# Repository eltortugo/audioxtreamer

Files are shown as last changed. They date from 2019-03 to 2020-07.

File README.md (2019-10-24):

# AudioXtreamer
A simple multichannel USB/FPGA PCM audio interface:

<p align="center">
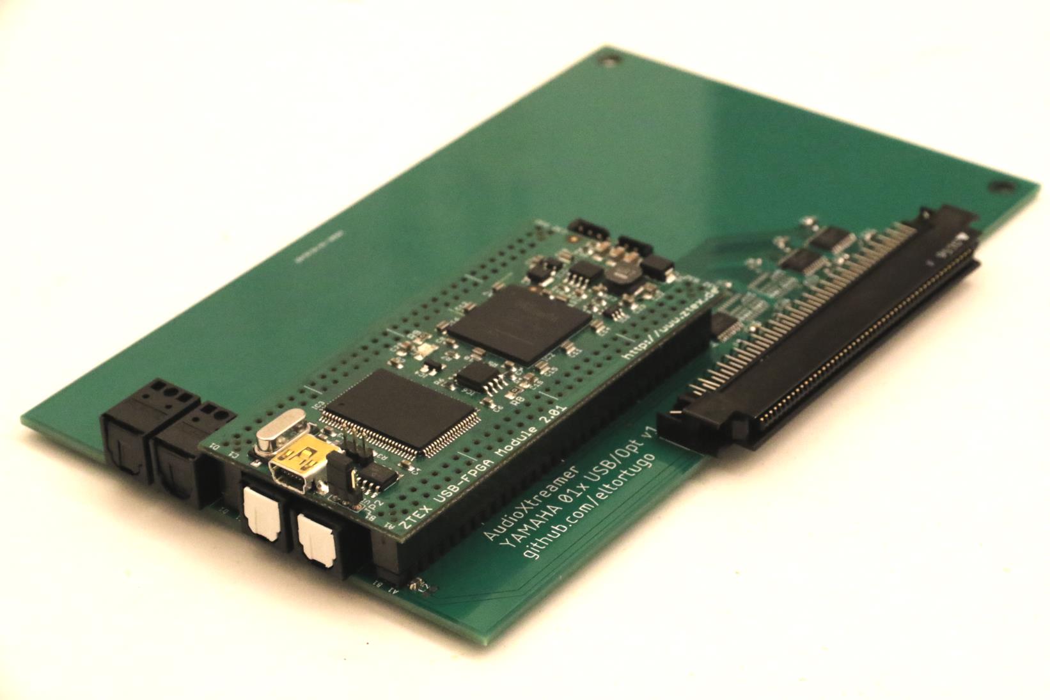
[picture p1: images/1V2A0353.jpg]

</p>

Initially started as a simple way to add usb connectivity to the Yamaha 01x firewire based digital mixer & control surface, this project attempts to provide a simple low latency ASIO interface to a usb connected fpga that handles the i2s I/O.

Inspired by [Koon](https://sites.google.com/site/koonaudioprojects/usb-to-multi-channel-usb2-0) and his 24ch out usb interface, it builds further by providing 32in/32out on a simple usb2.0 interface and bypassing any vendor specific driver to communicate with the lowest possible latency with the fpga.

The proof of concept was built and written around the ft232h usb fifo in combination with a zynq fpga but it rapidly became clear that from a practical point of view, a more flexible Cypress FX2LP and a Xilinx Spartan 6 would suffice the needs of the interface. Although the code is now fully adapted to the 16bit data bus of the Cypress and the CoreGenerator fifos of ISE, it is easily portable to the original 8 bit FTDI and the new Vivado IP generator.

The AudioXtreamer can be seen as 3 different parts:
  - A generic C++ ASIO (TortugASIO) multi-threaded 32/64 bit driver that bridges the audio client/DAW to the USB backend
  - AudioXtreamer is a simple user mode driver that uses isochronous transfers to communicate with the fx2lp, plus a tray UI to          configure asio buffer sizes, channel count and midi ports. It uses USBDk/WinUSB as backend layer to the FX2LP.
  - VHDL fpga code for the Spartan 6 which handles the usb fifos, sample buffer and generation and decoding of the PCM I/O
  
The sources are written in such a way that the user can configure how many inputs and outputs can be handled in software and hardware.
 
To build the whole project you will need basic knowledge of C/C++ and Visual Studio, VHDL and ISE plus basic digital electronics skills.
 
The hardware implementation is based on the [ZTEX 2.01](https://www.ztex.de/usb-fpga-2/usb-fpga-2.01.e.html) but simple Aliexpress fx2lp / spartan6 parts should also work with minimal effort.

Xtreamer and ZTEX module for 01x |  PCB
:-------------------------:|:-------------------------:
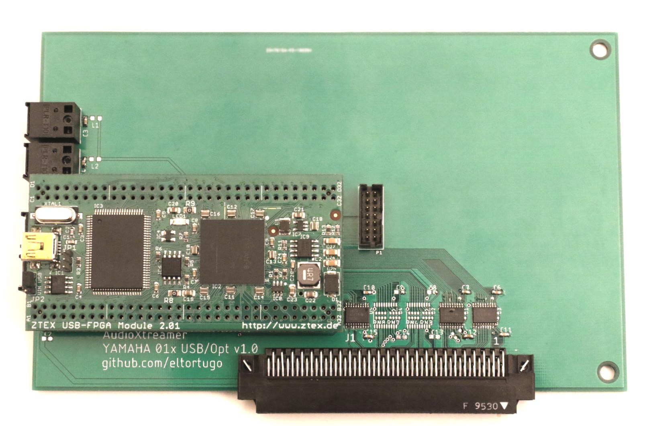
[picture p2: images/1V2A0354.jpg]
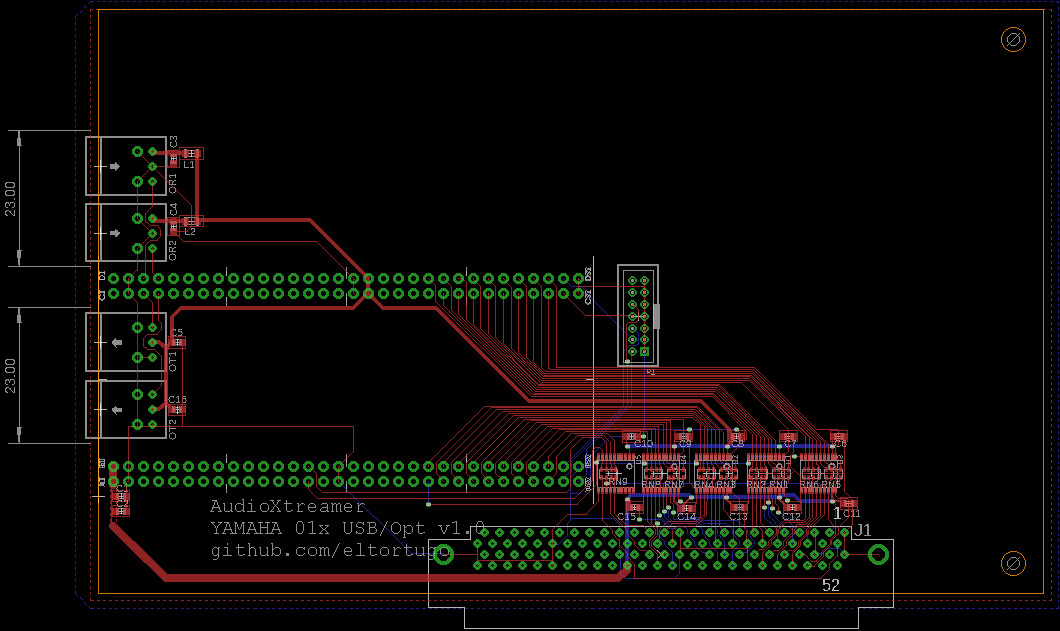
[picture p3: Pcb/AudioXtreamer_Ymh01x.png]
Gerber
  | 
  
  <p align="center">
  Yamaha 01x retrofitted with AudioXtreamer (USB/ADAT)

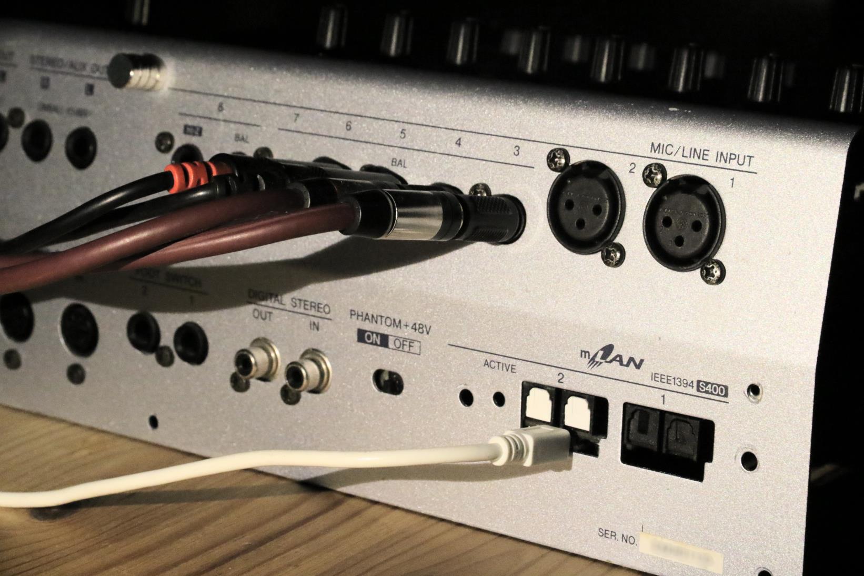
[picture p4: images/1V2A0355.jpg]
  
</p>

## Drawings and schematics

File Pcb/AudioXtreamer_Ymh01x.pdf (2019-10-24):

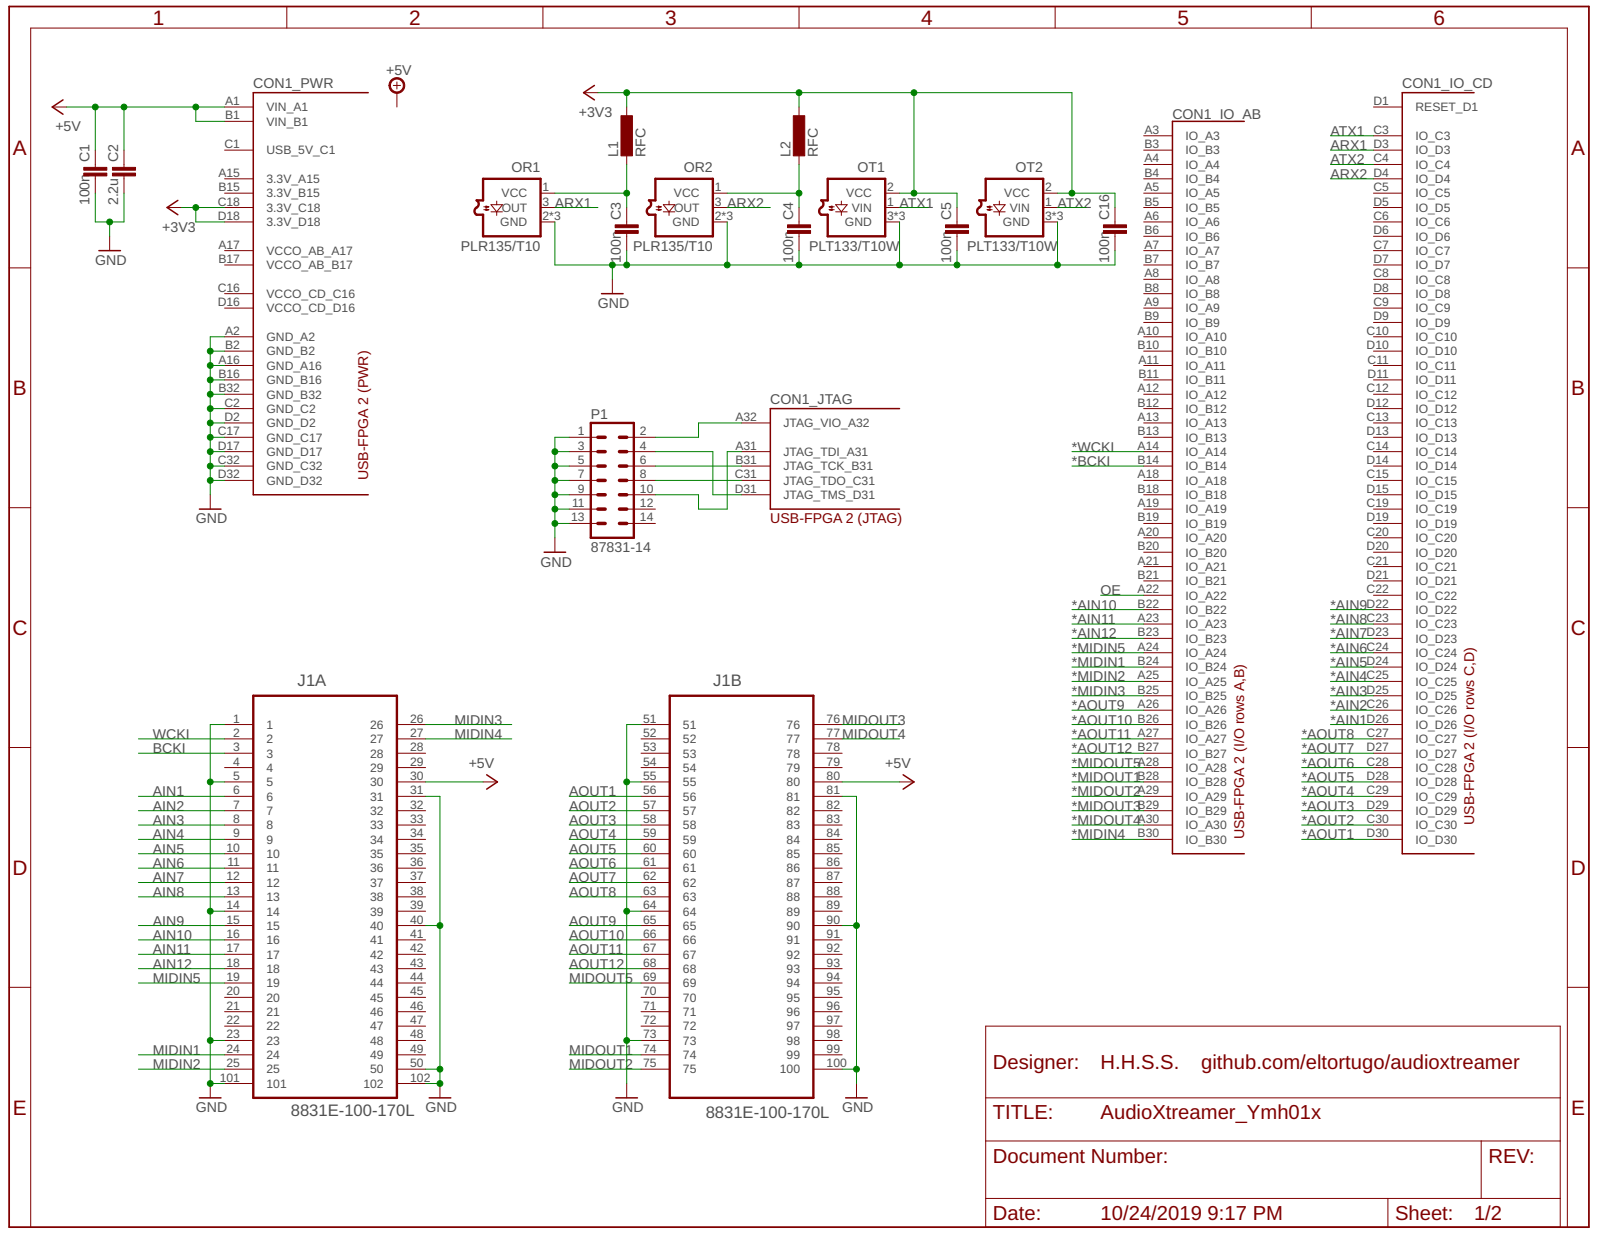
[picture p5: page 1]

Document Number: | REV:

Date: 10/24/2019 9:17 PM | Sheet: 1/2

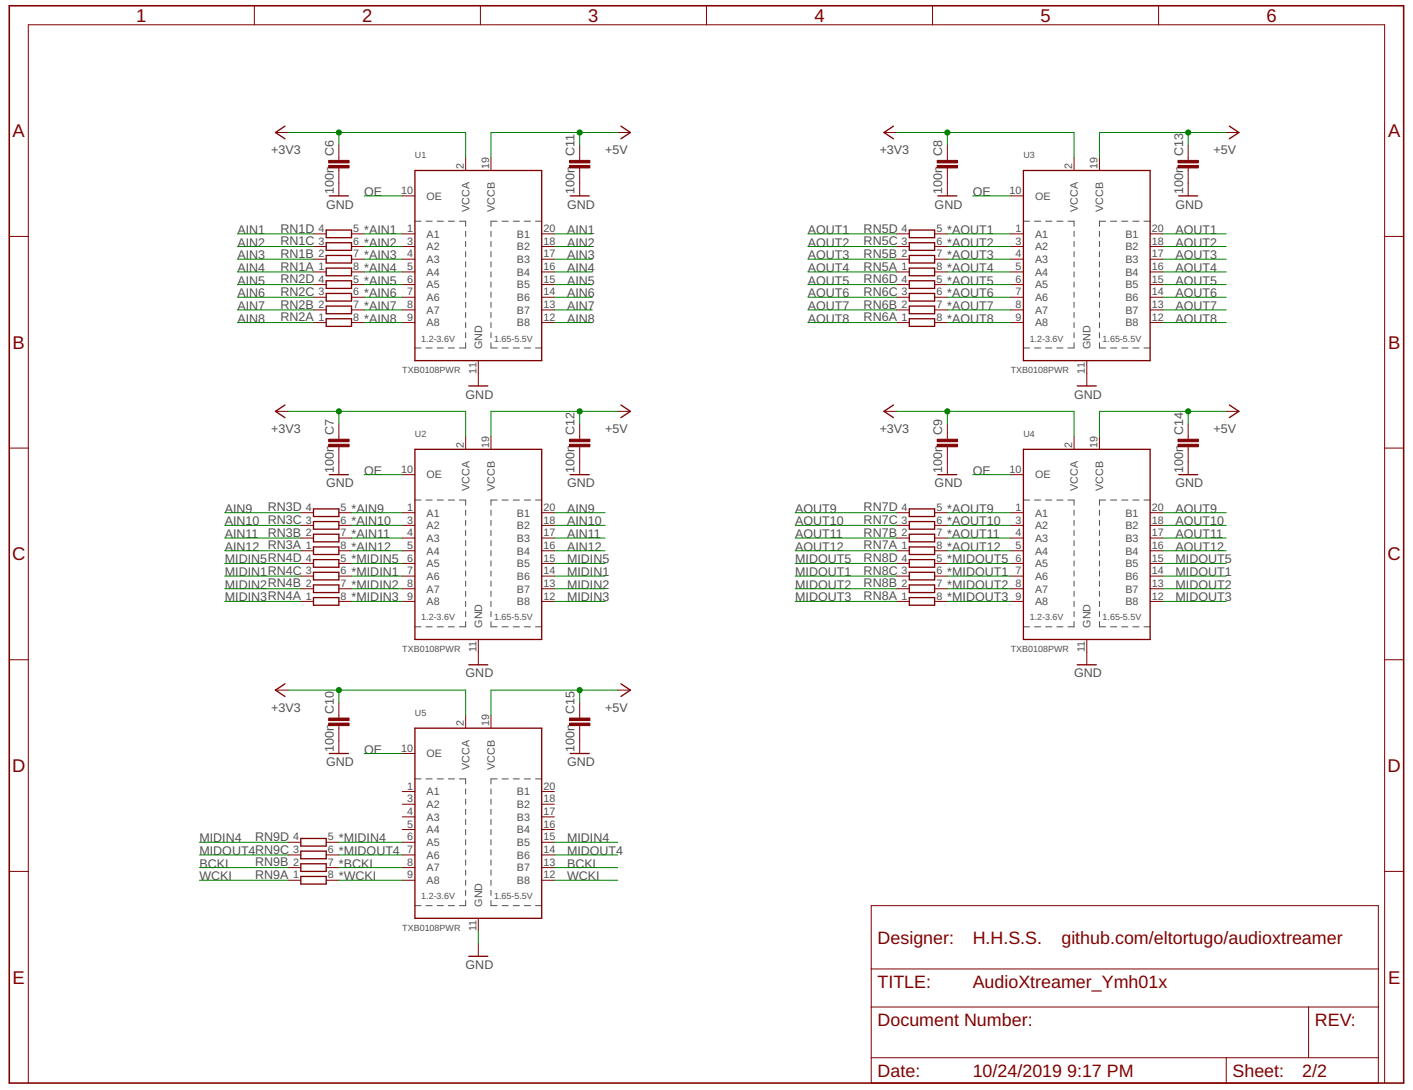
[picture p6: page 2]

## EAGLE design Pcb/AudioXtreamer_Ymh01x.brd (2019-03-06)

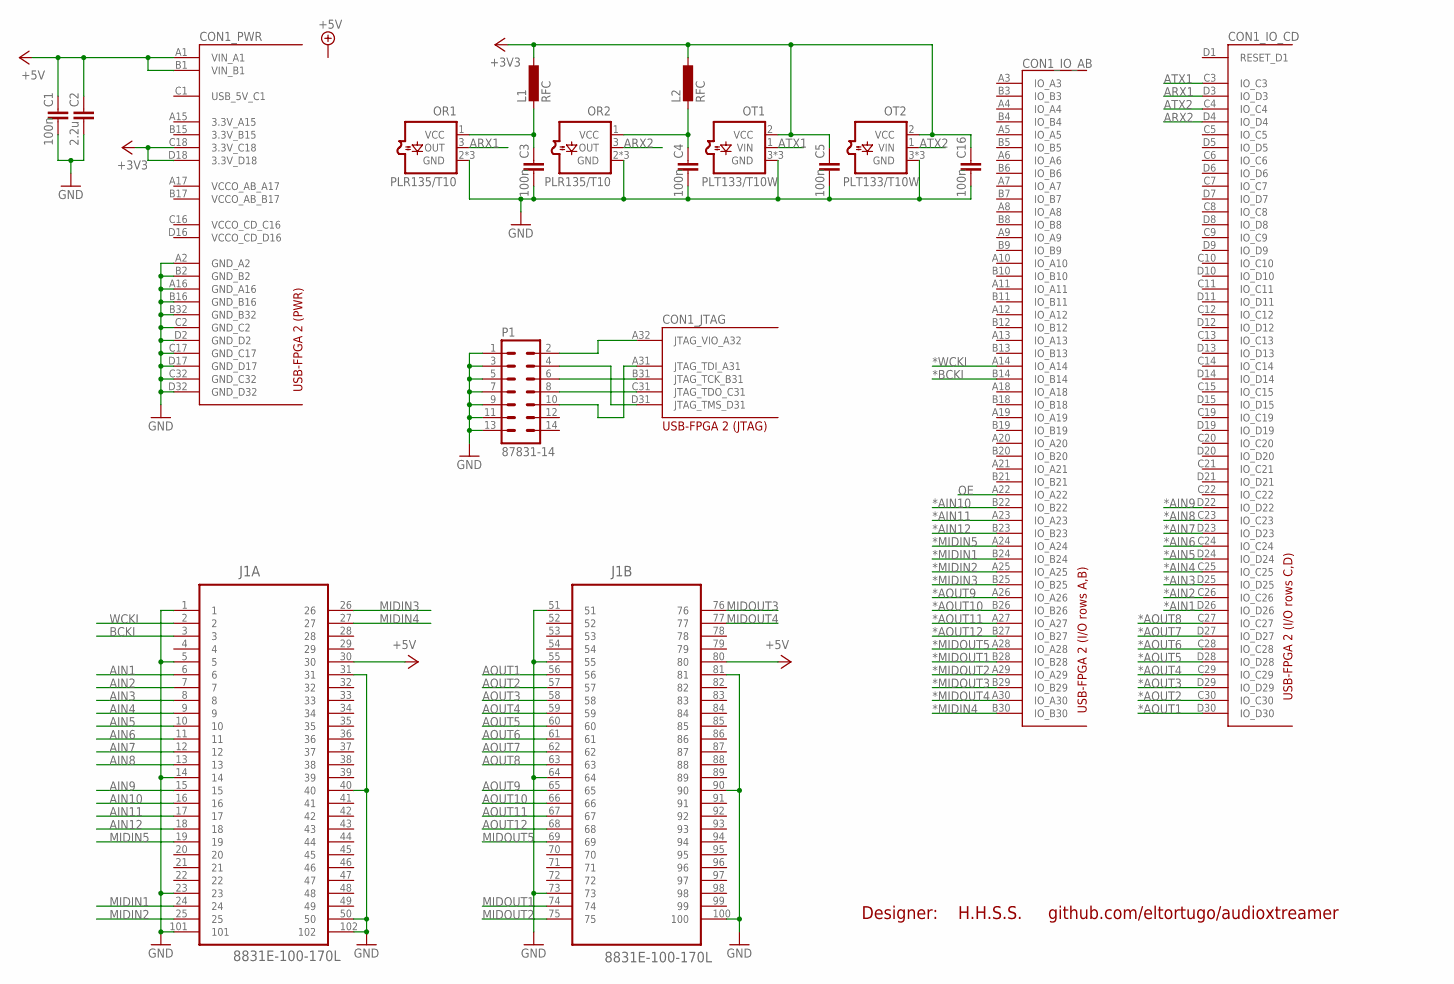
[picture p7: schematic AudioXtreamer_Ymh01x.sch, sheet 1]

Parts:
C1, C3, C4, C5, C16: 100n; C0603
C2: 2.2u; C0603
CON1: USB-FPGA-2THT; USB-FPGA-2-THT
J1: 8831E-100-170L; KEL_8831E-100-170L
L1, L2: RFC; L2012C
OR1, OR2: PLR135/T10
OT1, OT2: PLT133/T10W; PLT133/T10
P1: 87831-14

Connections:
*AIN1: CON1.D26 (IO_D26); also elsewhere on the board
*AIN2: CON1.C26 (IO_C26); also elsewhere on the board
*AIN3: CON1.D25 (IO_D25); also elsewhere on the board
*AIN4: CON1.C25 (IO_C25); also elsewhere on the board
*AIN5: CON1.D24 (IO_D24); also elsewhere on the board
*AIN6: CON1.C24 (IO_C24); also elsewhere on the board
*AIN7: CON1.D23 (IO_D23); also elsewhere on the board
*AIN8: CON1.C23 (IO_C23); also elsewhere on the board
*AIN9: CON1.D22 (IO_D22); also elsewhere on the board
*AIN10: CON1.B22 (IO_B22); also elsewhere on the board
*AIN11: CON1.A23 (IO_A23); also elsewhere on the board
*AIN12: CON1.B23 (IO_B23); also elsewhere on the board
*AOUT1: CON1.D30 (IO_D30); also elsewhere on the board
*AOUT2: CON1.C30 (IO_C30); also elsewhere on the board
*AOUT3: CON1.D29 (IO_D29); also elsewhere on the board
*AOUT4: CON1.C29 (IO_C29); also elsewhere on the board
*AOUT5: CON1.D28 (IO_D28); also elsewhere on the board
*AOUT6: CON1.C28 (IO_C28); also elsewhere on the board
*AOUT7: CON1.D27 (IO_D27); also elsewhere on the board
*AOUT8: CON1.C27 (IO_C27); also elsewhere on the board
*AOUT9: CON1.A26 (IO_A26); also elsewhere on the board
*AOUT10: CON1.B26 (IO_B26); also elsewhere on the board
*AOUT11: CON1.A27 (IO_A27); also elsewhere on the board
*AOUT12: CON1.B27 (IO_B27); also elsewhere on the board
*BCKI: CON1.B14 (IO_B14); also elsewhere on the board
*MIDIN1: CON1.B24 (IO_B24); also elsewhere on the board
*MIDIN2: CON1.A25 (IO_A25); also elsewhere on the board
*MIDIN3: CON1.B25 (IO_B25); also elsewhere on the board
*MIDIN4: CON1.B30 (IO_B30); also elsewhere on the board
*MIDIN5: CON1.A24 (IO_A24); also elsewhere on the board
*MIDOUT1: CON1.B28 (IO_B28); also elsewhere on the board
*MIDOUT2: CON1.A29 (IO_A29); also elsewhere on the board
*MIDOUT3: CON1.B29 (IO_B29); also elsewhere on the board
*MIDOUT4: CON1.A30 (IO_A30); also elsewhere on the board
*MIDOUT5: CON1.A28 (IO_A28); also elsewhere on the board
*WCKI: CON1.A14 (IO_A14); also elsewhere on the board
+3V3: C5.1, C16.1, CON1.C18 (3.3V_C18), CON1.D18 (3.3V_D18), L1.1, L2.1, OT1.2 (VCC), OT2.2 (VCC); also elsewhere on the board
+5V: C1.1, C2.1, CON1.A1 (VIN_A1), CON1.B1 (VIN_B1), J1.30, J1.80; also elsewhere on the board
AIN1: J1.6; also elsewhere on the board
AIN2: J1.7; also elsewhere on the board
AIN3: J1.8; also elsewhere on the board
AIN4: J1.9; also elsewhere on the board
AIN5: J1.10; also elsewhere on the board
AIN6: J1.11; also elsewhere on the board
AIN7: J1.12; also elsewhere on the board
AIN8: J1.13; also elsewhere on the board
AIN9: J1.15; also elsewhere on the board
AIN10: J1.16; also elsewhere on the board
AIN11: J1.17; also elsewhere on the board
AIN12: J1.18; also elsewhere on the board
AOUT1: J1.56; also elsewhere on the board
AOUT2: J1.57; also elsewhere on the board
AOUT3: J1.58; also elsewhere on the board
AOUT4: J1.59; also elsewhere on the board
AOUT5: J1.60; also elsewhere on the board
AOUT6: J1.61; also elsewhere on the board
AOUT7: J1.62; also elsewhere on the board
AOUT8: J1.63; also elsewhere on the board
AOUT9: J1.65; also elsewhere on the board
AOUT10: J1.66; also elsewhere on the board
AOUT11: J1.67; also elsewhere on the board
AOUT12: J1.68; also elsewhere on the board
ARX1: CON1.D3 (IO_D3), OR1.3 (OUT)
ARX2: CON1.D4 (IO_D4), OR2.3 (OUT)
ATX1: CON1.C3 (IO_C3), OT1.1 (VIN)
ATX2: CON1.C4 (IO_C4), OT2.1 (VIN)
BCKI: J1.3; also elsewhere on the board
GND: C1.2, C2.2, C3.2, C4.2, C5.2, C16.2, CON1.A2 (GND_A2), CON1.A16 (GND_A16), CON1.B2 (GND_B2), CON1.B16 (GND_B16), CON1.B32 (GND_B32), CON1.C2 (GND_C2), CON1.C17 (GND_C17), CON1.C32 (GND_C32), CON1.D2 (GND_D2), CON1.D17 (GND_D17), CON1.D32 (GND_D32), J1.1, J1.5, J1.14, J1.23, J1.31, J1.40, J1.50, J1.51, J1.55, J1.64, J1.73, J1.81, J1.90, J1.100, J1.101, J1.102, OR1.2 (GND), OR1.NC1 (GND), OR1.NC2 (GND), OR2.2 (GND), OR2.NC1 (GND), OR2.NC2 (GND), OT1.3 (GND), OT1.NC1 (GND), OT1.NC2 (GND), OT2.3 (GND), OT2.NC1 (GND), OT2.NC2 (GND), P1.1, P1.3, P1.5, P1.7, P1.9, P1.11, P1.13; also elsewhere on the board
MIDIN1: J1.24; also elsewhere on the board
MIDIN2: J1.25; also elsewhere on the board
MIDIN3: J1.26; also elsewhere on the board
MIDIN4: J1.27; also elsewhere on the board
MIDIN5: J1.19; also elsewhere on the board
MIDOUT1: J1.74; also elsewhere on the board
MIDOUT2: J1.75; also elsewhere on the board
MIDOUT3: J1.76; also elsewhere on the board
MIDOUT4: J1.77; also elsewhere on the board
MIDOUT5: J1.69; also elsewhere on the board
unnamed: CON1.A32 (JTAG_VIO_A32), P1.2
unnamed: CON1.D31 (JTAG_TMS_D31), P1.4
unnamed: CON1.B31 (JTAG_TCK_B31), P1.6
unnamed: CON1.C31 (JTAG_TDO_C31), P1.8
unnamed: CON1.A31 (JTAG_TDI_A31), P1.10
unnamed: C3.1, L1.2, OR1.1 (VCC)
unnamed: C4.1, L2.2, OR2.1 (VCC)
OE: CON1.A22 (IO_A22); also elsewhere on the board
WCKI: J1.2; also elsewhere on the board

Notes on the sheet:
Designer:

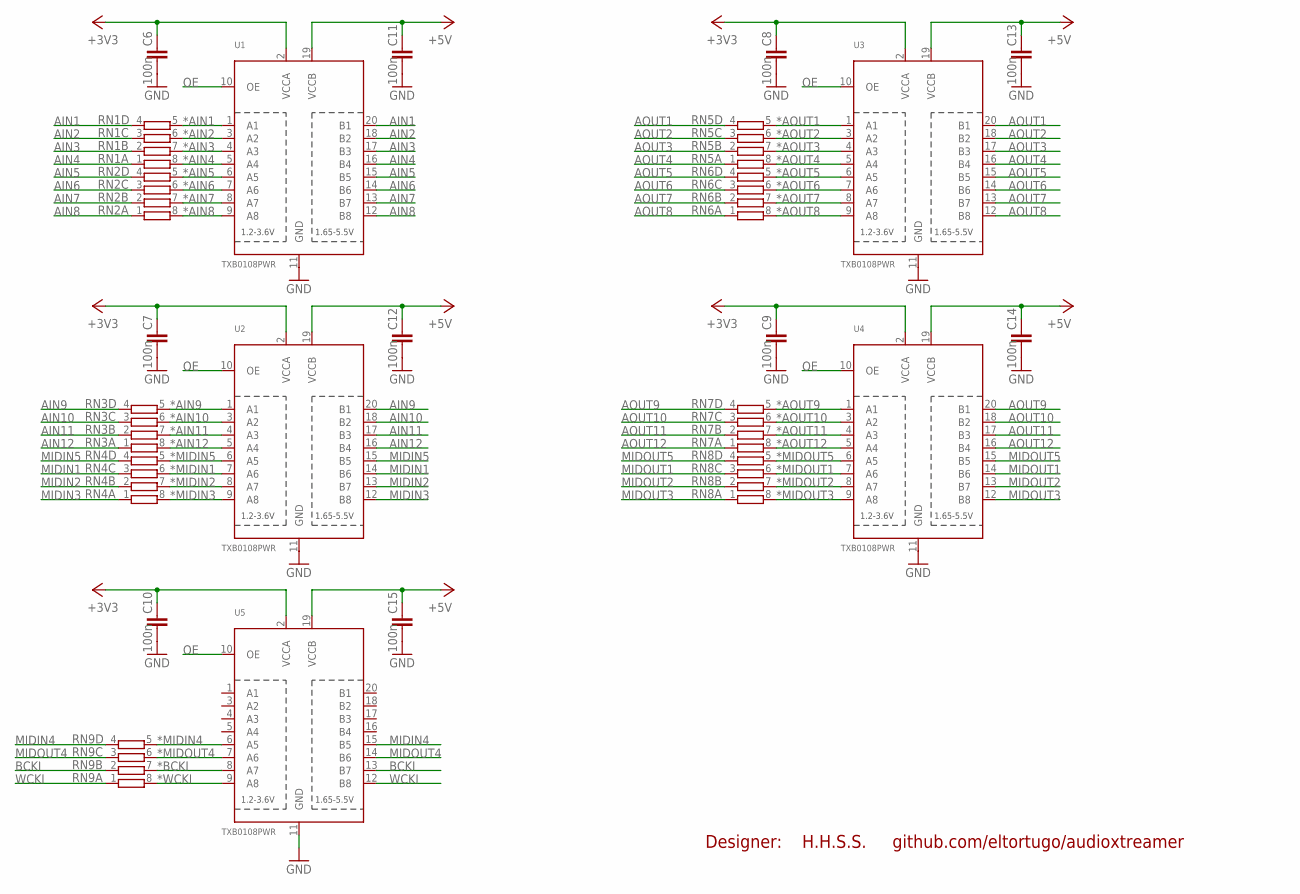
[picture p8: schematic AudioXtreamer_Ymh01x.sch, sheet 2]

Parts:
C6, C7, C8, C9, C10, C11, C12, C13, C14, C15: 100n; C0603
RN1, RN2, RN3, RN4, RN5, RN6, RN7, RN8, RN9: 4R-N0603-ARC; 0603-ARC
U1, U2, U3, U4, U5: TXB0108PWR; TSSOP20

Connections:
*AIN1: RN1.5 (2), U1.1 (A1); also elsewhere on the board
*AIN2: RN1.6 (2), U1.3 (A2); also elsewhere on the board
*AIN3: RN1.7 (2), U1.4 (A3); also elsewhere on the board
*AIN4: RN1.8 (2), U1.5 (A4); also elsewhere on the board
*AIN5: RN2.5 (2), U1.6 (A5); also elsewhere on the board
*AIN6: RN2.6 (2), U1.7 (A6); also elsewhere on the board
*AIN7: RN2.7 (2), U1.8 (A7); also elsewhere on the board
*AIN8: RN2.8 (2), U1.9 (A8); also elsewhere on the board
*AIN9: RN3.5 (2), U2.1 (A1); also elsewhere on the board
*AIN10: RN3.6 (2), U2.3 (A2); also elsewhere on the board
*AIN11: RN3.7 (2), U2.4 (A3); also elsewhere on the board
*AIN12: RN3.8 (2), U2.5 (A4); also elsewhere on the board
*AOUT1: RN5.5 (2), U3.1 (A1); also elsewhere on the board
*AOUT2: RN5.6 (2), U3.3 (A2); also elsewhere on the board
*AOUT3: RN5.7 (2), U3.4 (A3); also elsewhere on the board
*AOUT4: RN5.8 (2), U3.5 (A4); also elsewhere on the board
*AOUT5: RN6.5 (2), U3.6 (A5); also elsewhere on the board
*AOUT6: RN6.6 (2), U3.7 (A6); also elsewhere on the board
*AOUT7: RN6.7 (2), U3.8 (A7); also elsewhere on the board
*AOUT8: RN6.8 (2), U3.9 (A8); also elsewhere on the board
*AOUT9: RN7.5 (2), U4.1 (A1); also elsewhere on the board
*AOUT10: RN7.6 (2), U4.3 (A2); also elsewhere on the board
*AOUT11: RN7.7 (2), U4.4 (A3); also elsewhere on the board
*AOUT12: RN7.8 (2), U4.5 (A4); also elsewhere on the board
*BCKI: RN9.7 (2), U5.8 (A7); also elsewhere on the board
*MIDIN1: RN4.6 (2), U2.7 (A6); also elsewhere on the board
*MIDIN2: RN4.7 (2), U2.8 (A7); also elsewhere on the board
*MIDIN3: RN4.8 (2), U2.9 (A8); also elsewhere on the board
*MIDIN4: RN9.5 (2), U5.6 (A5); also elsewhere on the board
*MIDIN5: RN4.5 (2), U2.6 (A5); also elsewhere on the board
*MIDOUT1: RN8.6 (2), U4.7 (A6); also elsewhere on the board
*MIDOUT2: RN8.7 (2), U4.8 (A7); also elsewhere on the board
*MIDOUT3: RN8.8 (2), U4.9 (A8); also elsewhere on the board
*MIDOUT4: RN9.6 (2), U5.7 (A6); also elsewhere on the board
*MIDOUT5: RN8.5 (2), U4.6 (A5); also elsewhere on the board
*WCKI: RN9.8 (2), U5.9 (A8); also elsewhere on the board
+3V3: C6.1, C7.1, C8.1, C9.1, C10.1, U1.2 (VCCA), U2.2 (VCCA), U3.2 (VCCA), U4.2 (VCCA), U5.2 (VCCA); also elsewhere on the board
+5V: C11.1, C12.1, C13.1, C14.1, C15.1, U1.19 (VCCB), U2.19 (VCCB), U3.19 (VCCB), U4.19 (VCCB), U5.19 (VCCB); also elsewhere on the board
AIN1: RN1.4 (1), U1.20 (B1); also elsewhere on the board
AIN2: RN1.3 (1), U1.18 (B2); also elsewhere on the board
AIN3: RN1.2 (1), U1.17 (B3); also elsewhere on the board
AIN4: RN1.1, U1.16 (B4); also elsewhere on the board
AIN5: RN2.4 (1), U1.15 (B5); also elsewhere on the board
AIN6: RN2.3 (1), U1.14 (B6); also elsewhere on the board
AIN7: RN2.2 (1), U1.13 (B7); also elsewhere on the board
AIN8: RN2.1, U1.12 (B8); also elsewhere on the board
AIN9: RN3.4 (1), U2.20 (B1); also elsewhere on the board
AIN10: RN3.3 (1), U2.18 (B2); also elsewhere on the board
AIN11: RN3.2 (1), U2.17 (B3); also elsewhere on the board
AIN12: RN3.1, U2.16 (B4); also elsewhere on the board
AOUT1: RN5.4 (1), U3.20 (B1); also elsewhere on the board
AOUT2: RN5.3 (1), U3.18 (B2); also elsewhere on the board
AOUT3: RN5.2 (1), U3.17 (B3); also elsewhere on the board
AOUT4: RN5.1, U3.16 (B4); also elsewhere on the board
AOUT5: RN6.4 (1), U3.15 (B5); also elsewhere on the board
AOUT6: RN6.3 (1), U3.14 (B6); also elsewhere on the board
AOUT7: RN6.2 (1), U3.13 (B7); also elsewhere on the board
AOUT8: RN6.1, U3.12 (B8); also elsewhere on the board
AOUT9: RN7.4 (1), U4.20 (B1); also elsewhere on the board
AOUT10: RN7.3 (1), U4.18 (B2); also elsewhere on the board
AOUT11: RN7.2 (1), U4.17 (B3); also elsewhere on the board
AOUT12: RN7.1, U4.16 (B4); also elsewhere on the board
BCKI: RN9.2 (1), U5.13 (B7); also elsewhere on the board
GND: C6.2, C7.2, C8.2, C9.2, C10.2, C11.2, C12.2, C13.2, C14.2, C15.2, U1.11 (GND), U2.11 (GND), U3.11 (GND), U4.11 (GND), U5.11 (GND); also elsewhere on the board
MIDIN1: RN4.3 (1), U2.14 (B6); also elsewhere on the board
MIDIN2: RN4.2 (1), U2.13 (B7); also elsewhere on the board
MIDIN3: RN4.1, U2.12 (B8); also elsewhere on the board
MIDIN4: RN9.4 (1), U5.15 (B5); also elsewhere on the board
MIDIN5: RN4.4 (1), U2.15 (B5); also elsewhere on the board
MIDOUT1: RN8.3 (1), U4.14 (B6); also elsewhere on the board
MIDOUT2: RN8.2 (1), U4.13 (B7); also elsewhere on the board
MIDOUT3: RN8.1, U4.12 (B8); also elsewhere on the board
MIDOUT4: RN9.3 (1), U5.14 (B6); also elsewhere on the board
MIDOUT5: RN8.4 (1), U4.15 (B5); also elsewhere on the board
OE: U1.10 (OE), U2.10 (OE), U3.10 (OE), U4.10 (OE), U5.10 (OE); also elsewhere on the board
WCKI: RN9.1, U5.12 (B8); also elsewhere on the board

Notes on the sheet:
Designer:

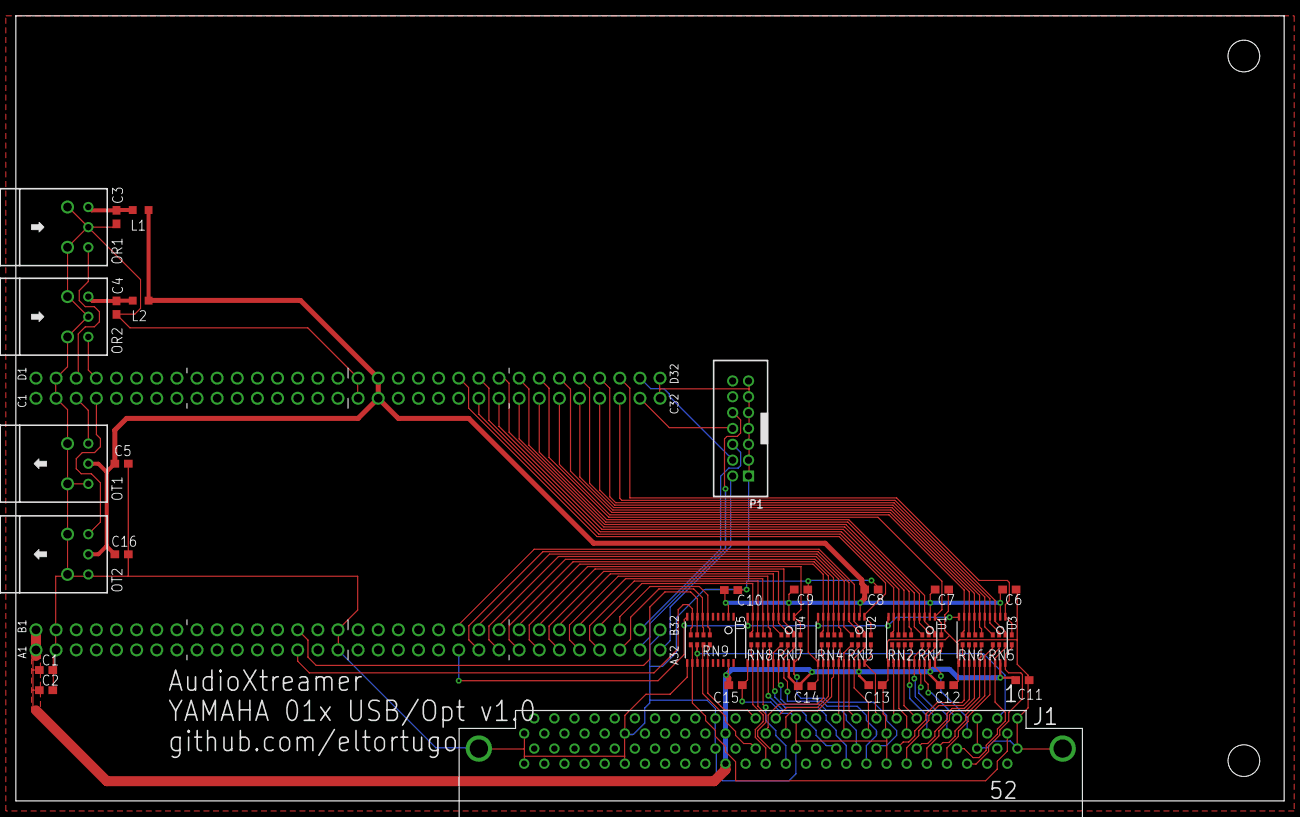
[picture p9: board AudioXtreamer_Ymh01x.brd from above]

Board: 2 copper layers, 160.0 x 99.0 mm, 39 parts (0 on the bottom side), 87 nets.

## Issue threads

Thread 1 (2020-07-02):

PCB issues

m0vse, 2020-07-02:
Hi, I am interested in building this but I have noticed a few issues with the PCB. Firstly the resistor networks, RNx appear to be mounted underneath the level shifter IC's, is this correct as I would have thought it would be better to mount them on the reverse of the board and use vias?

Also I have noticed that there don't seem to be any values for some of the passive components (RNx Lx) would you be able to add those to the schematic?

Looks like a great project and I look forward to getting it working with my 01X

m0vse, 2020-07-02:
It occurs to me that you have probably designed the board to have either level shifters or resistor networks so ignore that first bit!

Closed 2020-07-03.

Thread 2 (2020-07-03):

Cannot compile TortugASIO

m0vse, 2020-07-03:
I have been trying to compile the TortugASIO driver but it fails as it looks like it may rely on a modified asiosdk? It seems to be trying to use Unicode Windows calls in parts of asiosdk that doesn't support Unicode?

I get lots of this kind of error within the asiosdk register.cpp:

DWORD GetModuleFileNameW(HMODULE,LPWSTR,DWORD)': cannot convert argument 2 from 'char [360]' to 'LPWSTR'

Closed 2020-07-25.

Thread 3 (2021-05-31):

Cypress Device in endless loop

FriedemannVorwerk, 2021-05-31:
Hello Eltortugo,
I wanted to use your audioxtreamer board to record 16 MEMS-I2S-microphones at the same time.
After flashing the bitstream to the fpga and uploading the default firmware to the fifo, i used the local debugger in Visual Studio 2019 (Windows 10) and recognized, that the method "CypressDevice::Open" ran into an endless loop (no changes in the code).
Now I want to ask, if you used a dirrerend firmware for the cypress chip or if you can imagine what the problem could be.
Best regards.
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

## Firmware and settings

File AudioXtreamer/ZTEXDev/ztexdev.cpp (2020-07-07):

/*%
ZTEX Core API for C with examples
Copyright (C) 2009-2017 ZTEX GmbH.
http://www.ztex.de

This Source Code Form is subject to the terms of the Mozilla Public
License, v. 2.0. If a copy of the MPL was not distributed with this file,
You can obtain one at http://mozilla.org/MPL/2.0/.

Alternatively, the contents of this file may be used under the terms
of the GNU General Public License Version 3, as described below:

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
You should have received a copy of the GNU General Public License
along with this program; if not, see http://www.gnu.org/licenses/.
%*/

/// @file ztex.h 

/** @mainpage
@brief
The C Core API of the <a href="http://www.ztex.de/firmware-kit/index.e.html">ZTEX SDK</a>.
<p>
This API is used for developing host software in C. It is a re-implementation a subset of the <a href="../../java/index.html">JAVA API</a>.
<p>
<h2>Features</h2>
The main features are:
<ul>
<li> Full support of <a href="http://www.ztex.de/firmware-kit/default.e.html">Default Interface</a>
<ul>
<li> Multiple communication interfaces: high speed, low speed, GPIO's, reset signal
<li> Compatibility allows board independent host software
</ul>
</li>
<li> Bitstream upload directly to the FPGA
<li> Utility functions (gathering information about FPGA Boards, finding devices using filters, ...)
</ul>

<p>
<h2>Usage, Examples</h2>
The library consists in the single file pair 'ztex.c' and 'ztex.h'. It has been tested with gcc and should work with no/minor
modifications with other compilers.
<p>
Its recommended to link the application directly against the object file.
<p>
The package contains two examples, 'ucecho.c' and 'memfifo.c' which demonstrate the usage of the API including the default interface.
<p>
Object files and examples can be built using make. Under Windows it has been tested with MSYS/MinGW, see
<a href="http://wiki.ztex.de/doku.php?id=en:software:windows_hints#hints">Hints for Windows users</a>


<h2>Related Resources</h2>
Additional information can be found at
<ul>
<li> <a href="http://www.ztex.de/firmware-kit/index.e.html">ZTEX SDK</a>
<li> <a href="http://wiki.ztex.de/">ZTEX Wiki</a>
</ul>
*/

#include "stdafx.h"
#include <stdlib.h>
#include <stdio.h>
#include "ztexdev.h"

#include "UsbBackend.h"

#define SPRINTF_INIT( buf, maxlen )  	\
char* buf__ = buf;			\
int bufptr__ = 0;			\
int bufremain__ = maxlen-1;		\
buf__[0]=0;

#define SPRINTF_RETURN return bufptr__;

#define SPRINTF( ... ) { 						\
    if ( bufremain__>0 ) {						\
	int bufincr = snprintf(buf__+bufptr__,bufremain__, __VA_ARGS__ );	\
	if ( bufincr>0 ) {						\
	    if (bufincr > bufremain__) bufincr = bufremain__;		\
	    bufptr__+=bufincr;						\
	    bufremain__-=bufincr;					\
	    buf__[bufptr__] = 0;					\
	}								\
    }									\
}


// ******* ztex_get_device_info ************************************************
/** Get device information.
* @param handle device handle
* @param info structure where device information are stored.
* @return the error code or 0, if no error occurs.
*/
int ztex_get_device_info(HANDLE handle, ztex_device_info *info) {

  unsigned char *buf = info->product_string; // product string is used as buffer
  int64_t status;

  // VR 0x33: fast configuration info
  /*TWO_TRIES(status, control_transfer(handle, 0xc0, 0x33, 0, 0, buf, 128, 1500));
  info->fast_config_ep = status > 0 ? buf[0] : 0;
  info->fast_config_if = status == 2 ? buf[1] : 0;
  */
  // VR 0x3b: configuration data
  TWO_TRIES(status, control_transfer(handle, 0xc0, 0x3b, 0, 0, buf, 128, 1500));
  if (status < 0) status = control_transfer(handle, 0xc0, 0x3b, 0, 0, buf, 128, 1500);
  if ((status == 128) && (buf[0] == 67) && (buf[1] == 68) && (buf[2] == 48)) {
    info->fx_version = buf[3];
    info->board_series = buf[4];
    info->board_number = buf[5];
    info->board_variant[0] = buf[6];
    info->board_variant[1] = buf[7];
    info->board_variant[2] = 0;
  }
  else {
    info->fx_version = 0;
    info->board_series = 255;
    info->board_number = 255;
    info->board_variant[0] = 0;
  }

  // VR 0x64: default interface info
  TWO_TRIES(status, control_transfer(handle, 0xc0, 0x64, 0, 0, buf, 128, 1500));
  if (status>2 && buf[0]>0) {
    info->default_version1 = buf[0];
    info->default_version2 = status>3 ? buf[3] : 0;
    info->default_out_ep = buf[1] & 127;
    info->default_in_ep = buf[2] | 128;
  }
  else {
    info->default_version1 = 0;
    info->default_version2 = 0;
    info->default_out_ep = 255;
    info->default_in_ep = 255;
  }
  /*
  // string descriptors
  status = libusb_get_device_descriptor(libusb_get_device(handle), &dev_desc);
  if (status < 0) return status;
  if (libusb_get_string_descriptor_ascii(handle, dev_desc.iProduct, info->product_string, 128) < 0) info->product_string[0] = 0;
  if (libusb_get_string_descriptor_ascii(handle, dev_desc.iSerialNumber, info->sn_string, 64) < 0) info->sn_string[0] = 0;
  */
  return 0;
}


//// ******* ztex_print_device_info **********************************************
///** Print device info to a string.
//* The output may be truncated and is always null-terminated.
//* @param sbuf string buffer for output
//* @param sbuflen length of the string buffer
//* @param info structure where device information are stored.
//* @return length of the output string (may be truncated)
//*/
//int ztex_print_device_info(char* sbuf, int sbuflen, const ztex_device_info *info) {
//  SPRINTF_INIT(sbuf, sbuflen);
//  SPRINTF("Product: '%s'\n", info->product_string);
//  SPRINTF("Serial number: '%s'\n", info->sn_string);
//  SPRINTF("USB-Controller: %s\n", info->fx_version == 2 ? "EZ-USB FX2" : info->fx_version == 3 ? "EZ-USB FX3" : "unknown");
//  if ((info->board_series<255) && (info->board_number<255))
//    SPRINTF("Board: ZTEX USB-FPGA %d.%.2d%s\n", info->board_series, info->board_number, info->board_variant)
//  else
//    SPRINTF("Board: unknown\n")
//    if (info->fast_config_ep)
//      SPRINTF("High speed FPGA configuration: EP %d,  IF %d\n", info->fast_config_ep, info->fast_config_if)
//    else
//      SPRINTF("High speed FPGA configuration: not supported\n")
//      if ((info->default_version1>0))
//        SPRINTF("Default interface: v%d.%d,  OUT EP %d,  IN EP %d\n", info->default_version1, info->default_version2, info->default_out_ep & 127, info->default_in_ep & 127)
//      else
//        SPRINTF("Default interface: not available\n")
//        SPRINTF_RETURN;
//}


// ******* ztex_get_fpga_config ************************************************
/** Get device information.
* @param handle device handle
* @return <0 if an USB error occurred, 0 if unconfigured, 1 if configured
*/
int ztex_get_fpga_config(HANDLE handle) {
  unsigned char buf[16];
  int64_t status;
  TWO_TRIES(status, control_transfer(handle, 0xc0, 0x30, 0, 0, buf, 16, 1500));
  return status < 0 ? (int)status : status == 0 ? -255 : buf[0] == 0 ? 1 : 0;
}
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

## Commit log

2019-03-06 --eagle schematics and pcb layout files
    [YMH01x.brd, YMH01x.sch]
2019-03-07 -Added Settings dialog to select the channel count and the buffer size -Added ini file initialize settings to configure the AudioXtreamer and the settings DialogProc -Added a small Tray Icon to start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
    -FPGA pinout constraints based on the AudioXtreamer pcb
    -Implementation of the lsi interface and simulation to configure the xtreamer core instead of through the audio packets
    -tons of refactor i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
2019-03-23 AudioXtreamer: - this program is now the owner of the usb client and uses a memory mapped file to interchange the audio buffers with the asio driver. Named mutexes for synchronization. - There is now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
    TortugASIO:
    - All usb driver functionality moved out to AudioXtreamer and the asio driver now only communicates with it through memory mapped file, named mutexes and sendmessage
    - it is now possible to have a x64 dll to communicate with a x86 Xtreamer and viceversa.
2019-07-26 Isochronous IN /Bulk Out FIFO:(asynchronous audio)
    FIX: underrun at startup correct by precharging the output fifo
    FPGA: -output fifo cleanup and resize to 256 samples
    -coregen files versioned
    Xtreamer:
    -isoch xfers from 2 -> 4 , same for bulk out buffers, now with precharge
    -out fifo limited to 256 samples
    Fix: double reporting of disconnect
    Double buffering for the bulk transfer
    Cypress device is now backend connected an not anymore directly to usbdk
    Hybrid iso-in bulk-out(blocking) working
    ASIO/XTREAMER:
    - ASIO mutex replaced by two events for asynchronous asio Switch
    - initial work to make the usb backend usbdk/winusb capable
    - ztex bitsream cleanup
    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
2019-10-24 FEATURE: Full Iso in/out audio with MIDI
    CLEANUP: Main container rename
    ADDED: WinUSB/WinUSBHelper.cpp Backend
    CLEANUP: Move midi details to midi.cpp
    IMPROVEMENT: MMCSS priority time critical to worker thread
    ADDED: Schematics and Images
    FIX: Pipe abort after timeout solves lockup after usb cable disconnection/ hibernation
    IMPROVEMENT: MMCSS Pro Audio added to time critical threads
    IMPROVEMENT: Single solution for ASIO and Xtreamer Projects
    FIX: crash when no midi backend library found
    IMPROVEMENT: Critical section replaces mutex and switch loop minimal optimizations. CRT statically linked for testing purposes.
    CLEANUP: Usb Bulk calls removed.
    BUILDFIX: 32bit midi not linking due to wro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
    [AudioXtreamer_Ymh01x.brd, AudioXtreamer_Ymh01x.sch, YMH01x.sch]
2020-07-07 FEATURE: usb midi out decoder and running status encoder + test bench CLEANUP: moved echol to sim pkg
2020-07-07 IMPROVEMENT: usb_midi_in and usb_midi_out tested in a chain for complete closed loop verification
2020-07-07 FEATURE: Asynchronous ep0 request of sample rate
2020-07-07 FEATURE: UAC 2.0 audio in and out, feedback endpoint data is being polled by the ezusb on ep6 in interrupt for now. : packet headers discarded for compatibility with uac2.0. eof marker introduced for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
2020-07-07 IMPROVEMENT: Sample counter triggered now from the sof interrupt handler from the ezusb
2020-07-07 FEATURE: FX2LP has now alternate settings for the interfaces to reserve isoch bandwidth only when active. IN_PROGRESS: preparations for isoch in/out active only when asio client is connected. BUGFIX: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
2020-07-07 FEATURE: added support for 1024 samples ASIO buffer for compatibility with MixBUS BUILDFIX: installer relying on wrong arch file

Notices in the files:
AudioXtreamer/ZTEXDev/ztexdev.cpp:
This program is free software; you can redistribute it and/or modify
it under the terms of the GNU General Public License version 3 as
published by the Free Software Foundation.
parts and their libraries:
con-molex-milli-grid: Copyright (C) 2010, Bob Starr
